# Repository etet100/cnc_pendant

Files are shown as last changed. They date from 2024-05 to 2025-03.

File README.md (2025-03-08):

CNC pendant project to control my Genmitsu 4040 milling machine.

Main CHIP: ESP8266EX
AS5600 encoder based knob
3.2 inch capacitive touch display (https://www.buydisplay.com/3-2-inch-capacitive-touchscreen-240x320-tft-lcd-module-display)
I2C EEPROM for settings storage

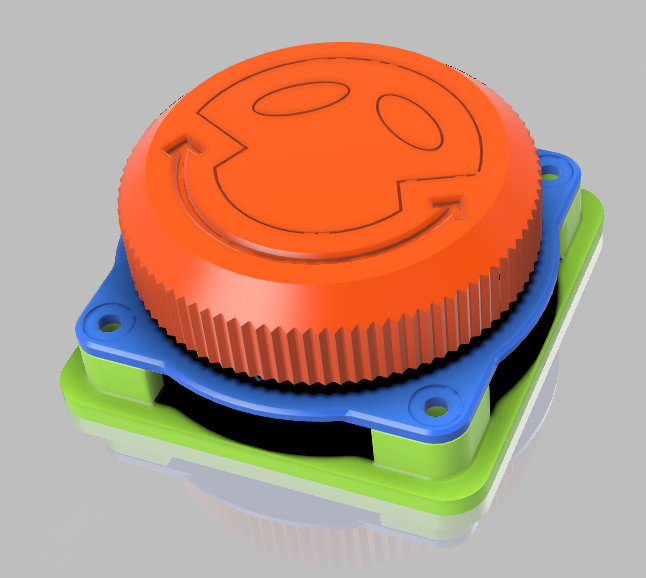
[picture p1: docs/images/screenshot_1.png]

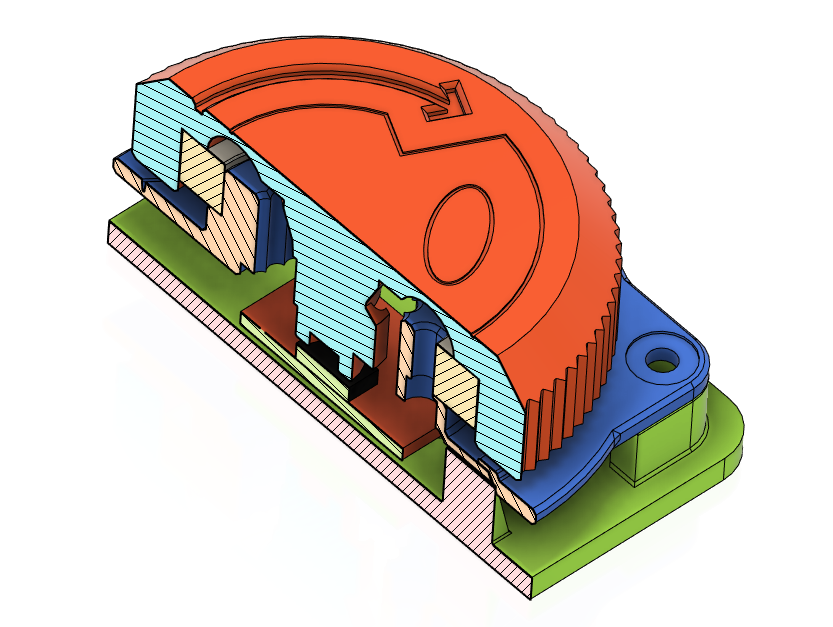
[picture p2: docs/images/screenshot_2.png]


Windows simulator/debugger

TCP Testing software:
Hercules
TcpTerminal

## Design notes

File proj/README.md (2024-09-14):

Projects of the UI modules, prerendered images (buttons, tags, etc.).

Requires fontawesome free edition for icons.

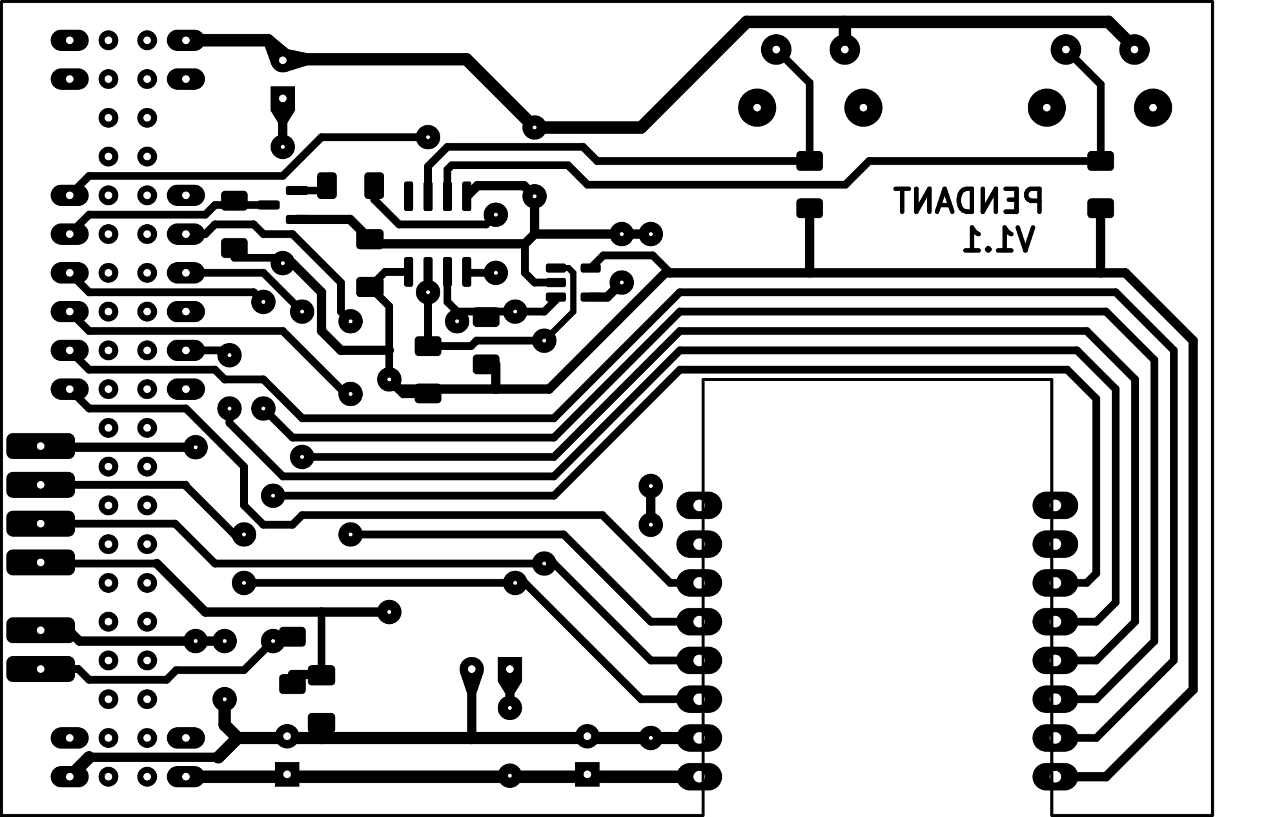
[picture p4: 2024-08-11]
pcb/main_v2/export/g14.png

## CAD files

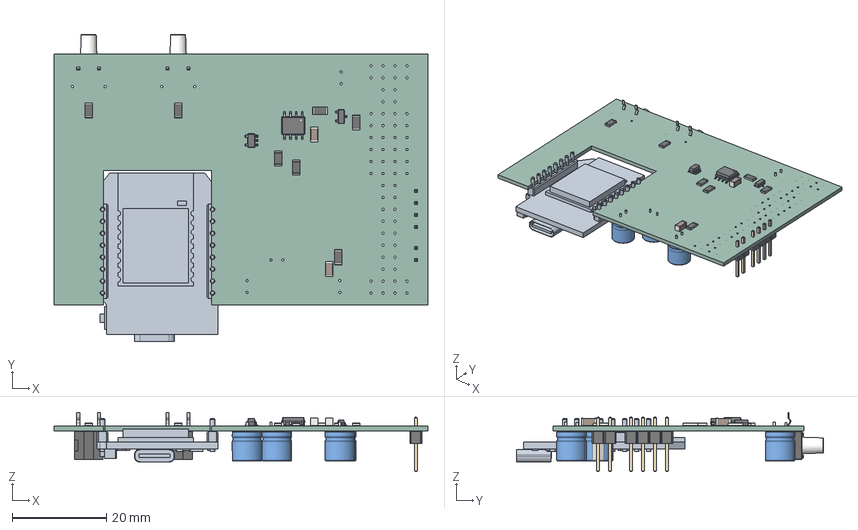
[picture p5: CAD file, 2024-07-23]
pcb/main_v2/main_v2.step
79.4 x 65.2 x 12.5 mm
C_1206_3216Metric x 2
R_1206_3216Metric x 7
SOIC_8_39x49mm_P127mm
SOT_23_5
SOT_23
CP_Radial_D63mm_P250mm x 4
Weemos_D1_Mini v9
PinHeader_1x04_P254mm_Vertical
TackSwitch v2 x 2
PinHeader_1x02_P254mm_Vertical
_autosave-main_v2_PCB

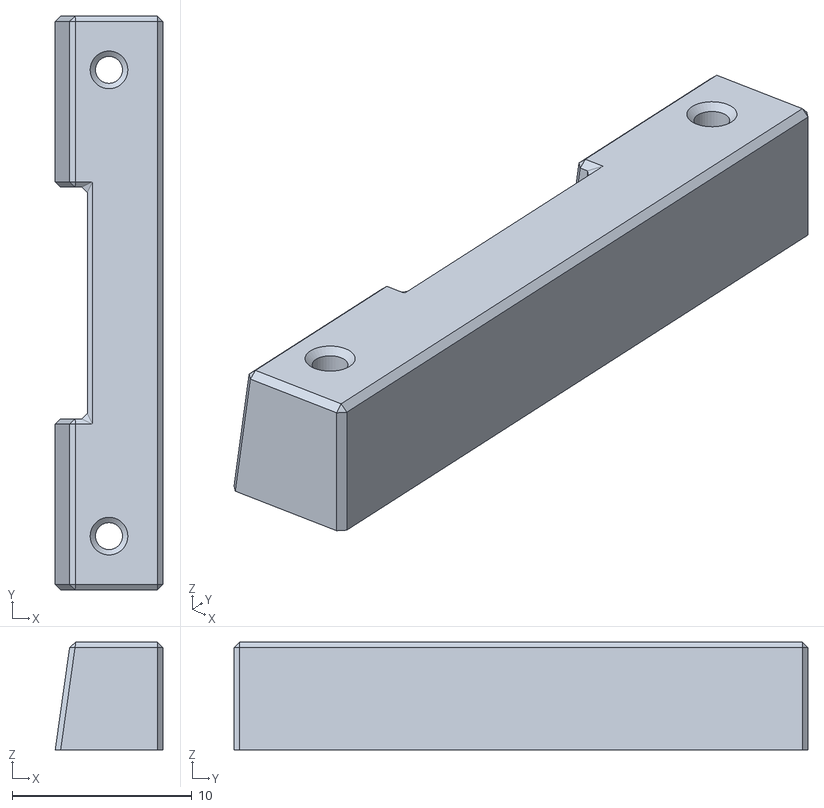
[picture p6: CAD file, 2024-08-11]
pcb/main_v2/Ust.stl
5.99 x 32.0 x 6.00

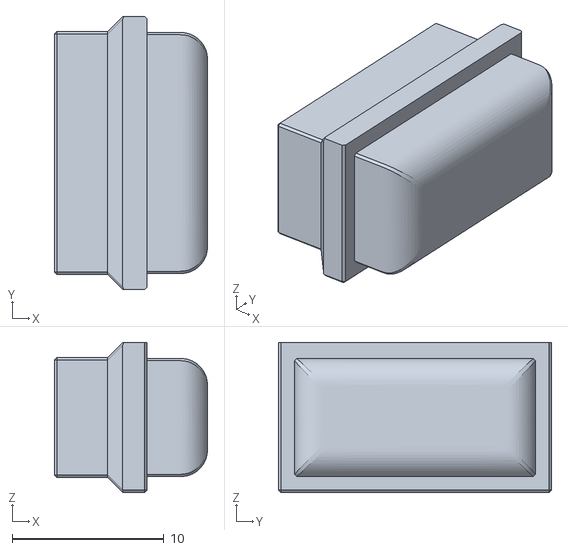
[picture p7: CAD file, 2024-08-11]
pcb/main_v2/Btn.stl
10.1 x 18.0 x 9.89

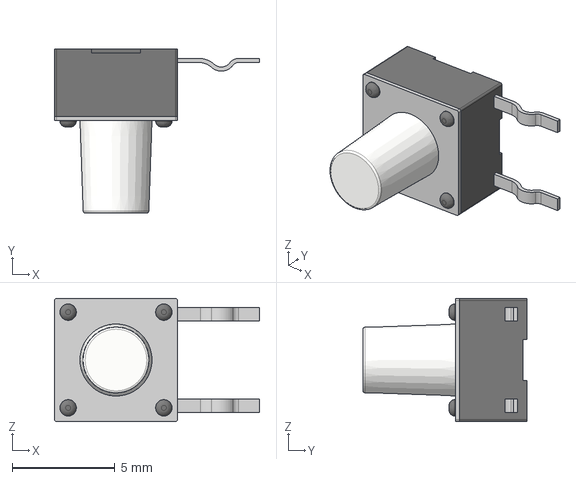
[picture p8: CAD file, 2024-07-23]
pcb/main_v2/TackSwitch.step
10.0 x 8.00 x 6.00 mm

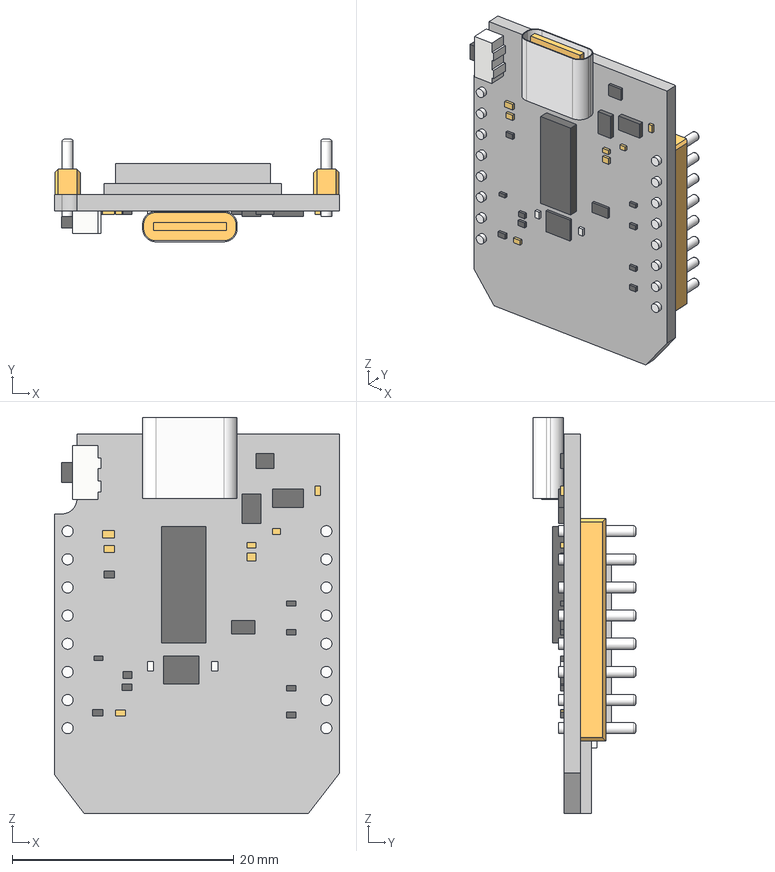
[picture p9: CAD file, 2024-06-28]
pcb/main_v2/Weemos_D1_Mini v9.step
25.7 x 9.26 x 35.7 mm
Board
USB C
Pins

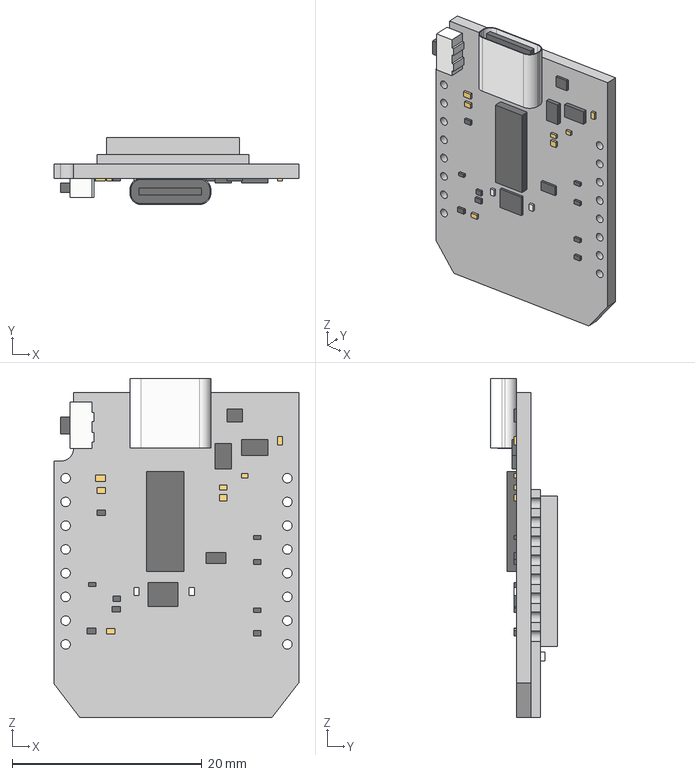
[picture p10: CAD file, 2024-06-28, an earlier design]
pcb/main_v2/Weemos_D1_Mini v7.step
25.7 x 7.06 x 35.7 mm
Board
USB C

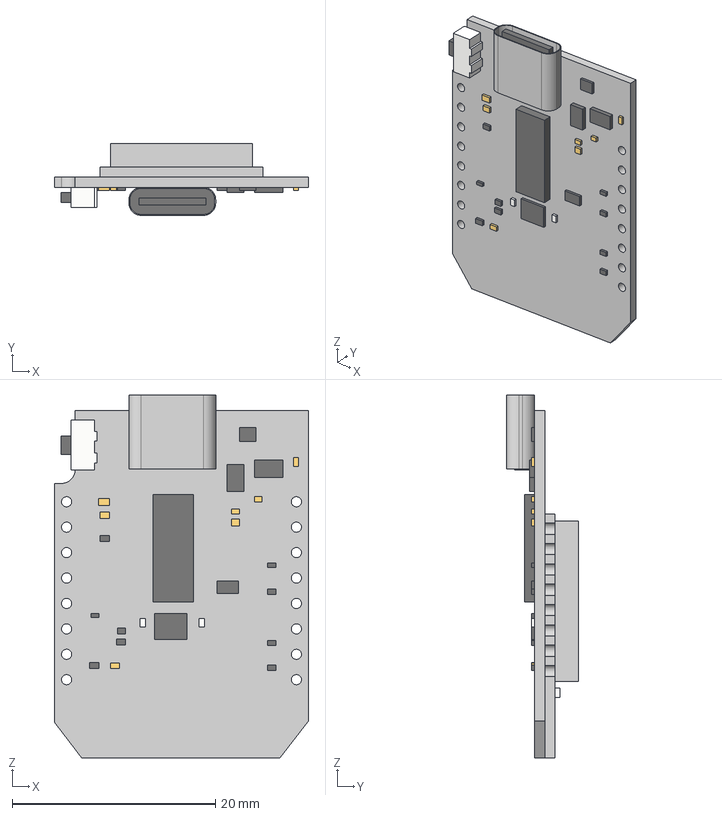
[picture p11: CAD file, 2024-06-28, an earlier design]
pcb/main_v2/Weemos_D1_Mini v2.step
25.0 x 7.06 x 35.7 mm
Board
USB C

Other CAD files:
pcb/main_v2/Weemos_D1_Mini v8.step

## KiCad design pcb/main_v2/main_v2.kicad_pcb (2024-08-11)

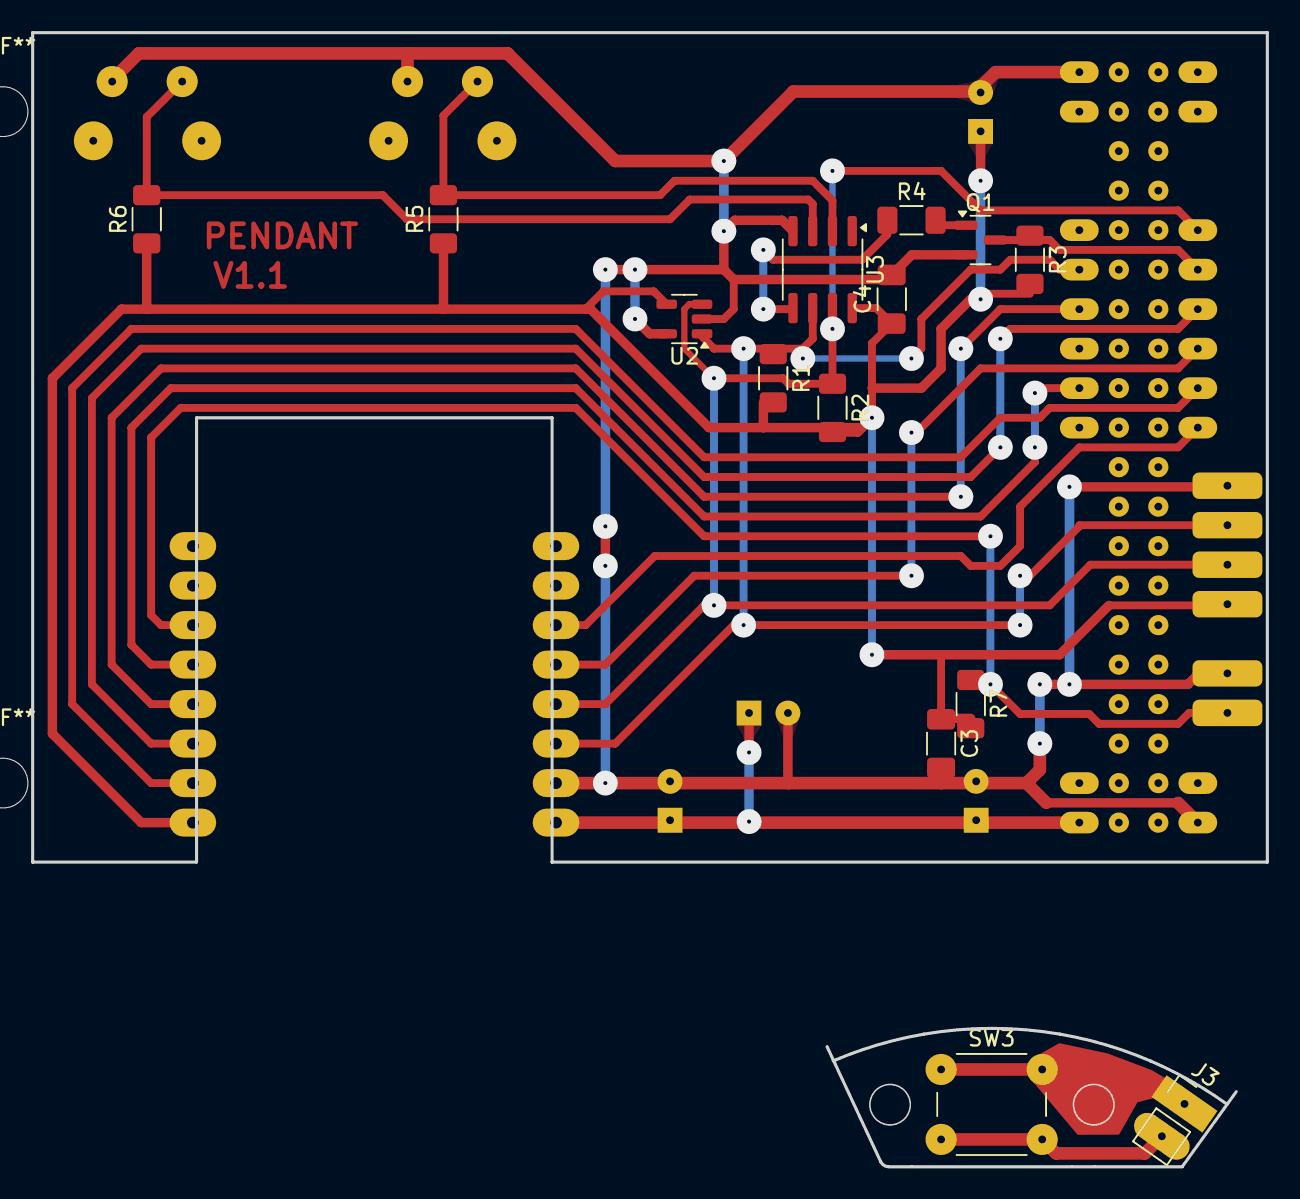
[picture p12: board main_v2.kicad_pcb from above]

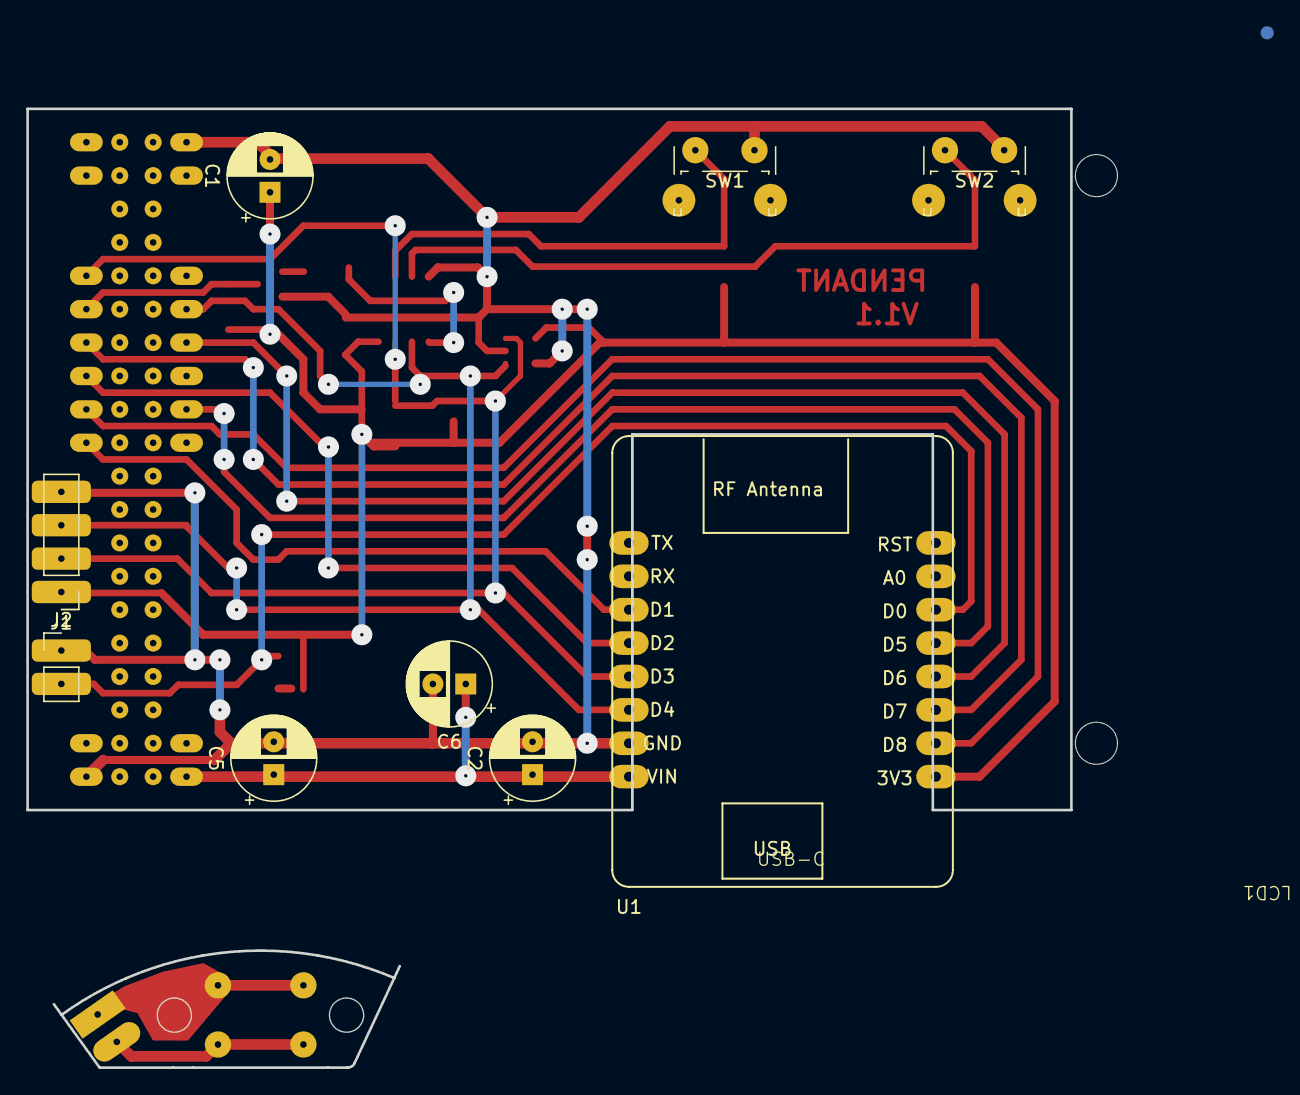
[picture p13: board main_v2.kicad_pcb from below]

Board: 2 copper layers, 79.4 x 53.3 mm, 24 parts (10 on the bottom side), 19 nets.

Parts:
C1, C2, C5, C6: 100uF; CP_Radial_D6.3mm_P2.50mm
C3, C4: 100n; C_1206_3216Metric_Pad1.33x1.80mm_HandSolder
J1: AS5600; PinHeader_1x04_P2.54mm_Vertical
J2, J3: Btn; PinHeader_1x02_P2.54mm_Vertical
LCD1: LCD
Q1: DMN3051L; SOT-23
R1, R2: 10k; R_1206_3216Metric_Pad1.30x1.75mm_HandSolder
R3, R5, R6, R7: 1k; R_1206_3216Metric_Pad1.30x1.75mm_HandSolder
R4: 180; R_1206_3216Metric_Pad1.30x1.75mm_HandSolder
SW1, SW2: SW_Push; SW_Tactile_SPST_Angled_PTS645Vx39-2LFS
SW3: SW_Push; SW_PUSH_6mm_H7.3mm
U1: NodeMCU_D1_Mini
U2: 24AA02-OT; SOT-23-5
U3: PCA9536D; SOIC-8_3.9x4.9mm_P1.27mm

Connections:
/SCL: J1.3, LCD1.30 (TOUCH_CLK), R1.1, U1.11 (SCL/D4), U2.1 (SCL), U3.6 (SCL)
/SDA: J1.2, LCD1.31 (TOUCH_DATA), R2.1, U1.12 (SDA/D3), U2.3 (SDA), U3.7 (SDA)
/VCC_3_3: C1.1, C3.1, C4.1, J1.1, R1.2, R2.2, R3.2, R5.1, R6.1, R7.2, U1.26 (3.3V), U2.4 (V_{CC}), U3.8 (VDD)
/VIN: C2.1, C5.1, C6.1, LCD1.2 (VCC), U1.30 (Vin)
GNDD: C1.2, C2.2, C3.2, C4.2, C5.2, C6.2, J1.4, J2.1, LCD1.1 (GND), LCD1.40 (GND), Q1.2 (S), SW1.2, SW2.2, U1.2 (GND), U2.2 (V_{SS}), U2.5 (WP), U3.4 (VSS)
unnamed: J2.2, R7.1, U1.15 (D0)
unnamed: J3.1, SW3.1
unnamed: J3.2, SW3.2
unnamed: LCD1.29 (LCD_BACKL), Q1.3 (D), R3.1
unnamed: LCD1.24 (LCD_CLK), U1.8 (D5)
unnamed: LCD1.23 (LCD_CS), U1.5 (D8)
unnamed: LCD1.25 (LCD_DC), U1.13 (D2)
unnamed: LCD1.27 (LCD_SDI), U1.6 (D7)
unnamed: LCD1.28 (LCD_SDO), U1.7 (D6)
unnamed: LCD1.21 (RST), U1.14 (D1)
unnamed: Q1.1 (G), R4.2
unnamed: R5.2, SW1.1, U3.2 (IO1)
unnamed: R6.2, SW2.1, U3.3 (IO2)
unnamed: R4.1, U3.5 (IO3)

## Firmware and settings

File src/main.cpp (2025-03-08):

#define MAIN

#ifdef WIN32
#include <QApplication>
#include "forms/testwindow.h"
#include <QThread>
#endif

#include <Arduino.h>
#include <HardwareSerial.h>
#include <Wire.h>
#include "app.h"
#include "screen.h"
#include "wirelesscommunicator.h"
#include "serial.h"
#include "mainpage.h"
#include "wheel.h"
#include "state.h"
#include "PCA9536D.h"
#include "buttons.h"
#include "I2C_eeprom.h"
#include "images.h"
#include "drawing.h"
#include "globals.h"

#define SDA_PIN D3
#define SCL_PIN D4
#define I2C_CLOCK 400000
#define LCD_BACKLIGHT_PIN 3

EventManager eventManager;
Touch touch(Wire);
App app(touch);
Screen screen;
WirelessCommmunicator wirelessCommmunicator;
SerialCommunicator serialCommunicator;
MainPage mainPage(screen);
Wheel wheel(Wire);
PCA9536 pca9536d;
Buttons buttons(pca9536d);
I2C_eeprom ee(0x50, I2C_DEVICESIZE_24LC08);

void logo(Screen &screen);
void setupSerial();
void setupTwoWire();
void setupWatchdog();

void setup()
{
    setupSerial();
    setupWatchdog();
    setupTwoWire();

    pca9536d.begin(Wire);
    if (pca9536d.isConnected())
    {
        // pca9536d.pinMode(0, OUTPUT); NC
        pca9536d.pinMode(LCD_BACKLIGHT_PIN, OUTPUT);
        pca9536d.write(LCD_BACKLIGHT_PIN, HIGH);
        Serial.println("PCA9536 connected");
    } else
    {
        Serial.println("PCA9536 not connected");
    }

    delay(100);

    ee.begin();
    if (!ee.isConnected()) {
        Serial.println("ERROR: Can't find eeprom\nstopped...");
        while (1);
    }

    Serial.println("\nTEST: determine size");
    uint32_t size = ee.determineSize(true);
    if (size > 0) {
        Serial.print("SIZE: ");
        Serial.print(size);
        Serial.println(" KB");
    } else if (size == 0) {
        Serial.println("WARNING: Can't determine eeprom size");
    } else {
        Serial.println("ERROR: Can't find eeprom\nstopped...");
        while (1);
    }

    wheel.begin();
    touch.begin();
    screen.begin();

    app.loop(buttons);
    pca9536d.write(LCD_BACKLIGHT_PIN, LOW);

    wirelessCommmunicator.begin();

    #ifdef LOGO
    logo(screen);
    #endif

    app.setCurrentPage(&mainPage);

    eventManager.addListener(EventType::PowerBtnPressed, [](int event, int param) {
        Serial.println("Power off");
        pca9536d.write(LCD_BACKLIGHT_PIN, HIGH);
    });

    // mainPage.onPowerOff([](int) {
    //     Serial.println("Power off");
    //     pca9536d.write(LCD_BACKLIGHT_PIN, HIGH);
    // });
    buttons.onWheelPressed([](int) {
        Serial.println("Power on");
        pca9536d.write(LCD_BACKLIGHT_PIN, LOW);
    });

    //ESP.deepSleep(0);

    buttons.begin();

    Serial.println("Setup done");
}

void setupSerial()
{
    Serial.begin(115200);
}

void setupTwoWire()
{
    Serial.println("Initializing I2C...");

    Wire.begin(SDA_PIN, SCL_PIN);
    Wire.setClock(I2C_CLOCK);
}

void setupWatchdog()
{
    Serial.println("Disabling watchdog...");

    #ifndef WIN32
    ESP.wdtDisable();
    *((volatile uint32_t*)0x60000900) &= ~(1); // Disable hardware WDT
    #endif
}

void loop()
{
    delay(15);

    static uint32_t lastTime = 0;
    if (millis() - lastTime >= 25) {
        state.setPos(Axis::X, (rand() % 500000) / 100.0);
        state.setPos(Axis::Y, (rand() % 500000) / 100.0);
        state.setPos(Axis::Z, (rand() % 500000) / 100.0);
        state.triggerUpdatedEvent();

        wirelessCommmunicator.loop();
        buttons.loop();
        app.loop(buttons);
        if (buttons.isTopPressed()) {
            Serial.println("Top button");
            //state.setPos(Z, 1);
        }
        if (buttons.isBottomPressed()) {
            Serial.println("Bottom button");
            //state.setPos(Z, 2);
        }
        // if (buttons.isWheelPressed()) {
        //     Serial.println("Wheel button");
        //     //state.setPos(Z, 3);
        // }
        // serialCommunicator.loop();
        wheel.loop();
        // state.setPos(Axis::X, wheel.getPosition());
        // state.setPos(Axis::Y, wheel.getSpeed());

        lastTime = millis();
    }

    eventManager.processAllEvents();
}

#ifdef WIN32

class Worker : public QThread
{
        public:
            void run() {
                setup();
                while (!m_stop) {
                    loop();
                }
                exit(0);
            }

            void stop() {
                m_stop = true;
                wait();
                m_stop = false;
            }

            void restart() {
                stop();
                start();
            }

        private:
            bool m_stop = false;
};

LcdWidget *lcd = nullptr;
TestWindow *wnd = nullptr;

int main(int argc, char *argv[])
{
    QApplication a(argc, argv);

    TestWindow tw;
    tw.show();

    wnd = &tw;
    lcd = tw.getLcdWidget();

    Worker worker;
    worker.start();

    worker.connect(
        &tw,
        &TestWindow::resetClicked,
        &worker,
        &Worker::restart
    );

    a.exec();

    worker.stop();

    return 0;
}

#endif

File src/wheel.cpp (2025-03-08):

#include "wheel.h"

#define WHEEL_STEP 136.5333333
#define WHEEL_OFFSET 10
#define WHEEL_POSITION 0
#define WHEEL_HISTERESIS (WHEEL_STEP * 0.7)

Wheel::Wheel(TwoWire& wire): wire(wire), as5600(&wire), position(WHEEL_POSITION) {
    updateThresholds(0);
}

void Wheel::updateThresholds(float position) {
    this->thresholdTop = position + WHEEL_HISTERESIS;
    this->thresholdBottom = position - WHEEL_HISTERESIS;
}

void Wheel::begin() {
    Serial.println("Initializing wheel...");

    as5600.begin();
    bool as5600connected = as5600.isConnected();

    Serial.print(" Result: ");
    Serial.println(as5600connected ? "connected" : "not connected");

    if (as5600connected) {
        int32_t basePos = as5600.getCumulativePosition() - WHEEL_OFFSET;
        while (true) {
            if (basePos > this->thresholdTop) {
                this->position++;
                updateThresholds(this->position * WHEEL_STEP);
            } else if (basePos < this->thresholdBottom) {
                this->position--;
                updateThresholds(this->position * WHEEL_STEP);
            } else {
                // debug();
                return;
            }
        }
    }
}

void Wheel::debug() {
    Serial.print(this->position, DEC);
    Serial.print(" ");
    Serial.print(this->thresholdBottom, DEC);
    Serial.print(" ");
    Serial.println(this->thresholdTop, DEC);
}

void Wheel::loop() {
    int32_t basePos = as5600.getCumulativePosition() - WHEEL_OFFSET;

    // do more than one step at a time
    while (true)
    {
        if (basePos > this->thresholdTop) {
            this->position++;
            updateThresholds(this->position * WHEEL_STEP);
            // debug();
        } else if (basePos < this->thresholdBottom) {
            this->position--;
            updateThresholds(this->position * WHEEL_STEP);
            // debug();
        } else {
            break;
        }
    }

    this->speed = this->as5600.getAngularSpeed();
}

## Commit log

2024-06-02 Wheel class
2024-06-29 pcb - lcd on wrong side
    [main_v2.kicad_pcb, main_v2.kicad_sch, main_v2.step]
2024-07-23 Buttons, drawing float, State, touch pos
2024-08-02 wheel position with hysteresis
2024-08-02 spi freq
2024-08-02 i2c eeprom test
2024-08-11 Fixed initital wheel position
    [wheel.cpp]
2024-08-11 PCB - small board
    [Btn.stl, Ust.stl, main_v2.kicad_pcb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]
2024-08-30 Fonts, buttons
2024-08-30 Wheel - do more than one step at a ti me
